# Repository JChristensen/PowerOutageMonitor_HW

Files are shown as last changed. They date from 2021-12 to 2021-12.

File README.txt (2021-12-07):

README file for Arduino-Based Power Outage Logger board v1.2
https://github.com/JChristensen/PowerOutageMonitor_HW
Jack Christensen Dec 2021

This work is licensed under the Creative Commons Attribution-ShareAlike 4.0
International License. To view a copy of this license, visit
https://creativecommons.org/licenses/by-sa/4.0/ or send a letter to
Creative Commons, 171 Second Street, Suite 300, San Francisco, CA 94105, USA.

================================================================================
The version 1.2 board has updated routing which supports RTC 1Hz interrupt
without adding a wire.

An Arduino sketch for the board can be found at:
https://github.com/JChristensen/PowerOutageMonitor_SW

Boards can be ordered from OSH Park,
https://oshpark.com/shared_projects/b4qpXvHG

================================================================================
Assembly notes and options

1. The board is intended to be powered by either a 5V or a 7-12V AC adapter.
When using a 5V adapter, it MUST BE REGULATED; in this case, C1, C2, D1 and U2
do not need to be installed. Set the PWR SEL jumper (JP1) to DIRECT when using a
5V regulated adapter.

2. When disconnected from the power, certain 5V regulated adapters may emit a
power blip that the RTC interprets as a power-up event. This results in the
power-down and power-up timestamps being identical even if the power is left off
for several minutes. To eliminate this, power the RTC from an MCU pin by
selecting MCU power via the RTC PWR jumper (JP2). This is supported by the
sketch referenced above. It is also recommended to set the ATmega328P brown-out
detector to 4.3V by setting the extended fuse byte to 0x04. Note that when the
RTC is powered from the MCU pin, any MCU reset will cause a power outage to be
logged, whether or not it is associated with an actual power outage.

3. The Tinsharp TC1602A-09T 16x2 LCD display uses an LED backlight that requires
only 15mA at 5V. This means that a current-limiting resistor is not needed (use
a jumper in place of R5), and that the backlight can be powered from an MCU pin.
Do not use displays that require more than 20mA to operate the backlight. Note
also that some displays will require a non-zero value for R5 if their backlight
operates on less than 5V.

4. The board includes optional provisions for an on-board temperature sensor and
associated pullup resistor (U3, R6). An optional three-position terminal block
can also connect to an off-board sensor. The Arduino sketch referenced above
contains no code for these optional sensors.

5. Photocell PC1 is used to adjust the display backlight brightness to match the
ambient light level. The Arduino sketch above uses the internal AVR pullup
resistor in association with PC1, but if this does not result in satisfactory
adjustment of the backlight, then the internal pullup can be disabled and an
alternate resistor can be installed at R4.

================================================================================
Power Outage Logger Board
Bill of Materials

Part    Value               Device
C1      47uF                Radial lead electrolytic, 16V, 2 mm lead spacing
C2      100nF               50V MLCC, 0.1 in. lead spacing
C3      47uF                Radial lead electrolytic, 16V, 2 mm lead spacing
C4      100nF               50V MLCC, 0.1 in. lead spacing
C5      100nF               50V MLCC, 0.1 in. lead spacing
C6      100nF               50V MLCC, 0.1 in. lead spacing
C7      100nF               50V MLCC, 0.1 in. lead spacing
C8      27pF                50V MLCC, 0.1 in. lead spacing
C9      27pF                50V MLCC, 0.1 in. lead spacing
C10     100nF               50V MLCC, 0.1 in. lead spacing
D1      1N4004              Silicon rectifier
D2      1N4148              Signal diode
D3      5mm LED
J1      2.1mm power jack
JP1     Supply select       1x3 0.1 in. male header (or use jumper)
JP2     RTC power select    1x3 0.1 in. male header, right angle (or use jumper)
JP3     FTDI                1x6 0.1 in. male header, right angle
JP4     ICSP                2x3 0.1 in. male header (OPTIONAL)
PC1     CdS Photocell
PCB1    MCP79412            MCP79412 RTC Breakout Board, see:
                            https://github.com/JChristensen/rtc79412
PCB2    TC1602A-09T         Tinsharp 16x2 LCD
R1      10K                 1/8W 5% carbon film
R2      10K                 3/8 in. square trimpot, Bourns 3386P or equivalent
R3      330Ω                1/8W 5% carbon film
R4      10K                 1/8W 5% carbon film,
                            OPTIONAL pullup resistor for photocell (sketch uses
                            internal AVR pullup).
R5      0Ω                  1/8W 5% carbon film, current-limiting resistor for
                            LCD backlight.
                            Use a jumper with the TC1602A-09T display. Use
                            appropriate value for other displays.
R6      4.7K                1/8W 5% carbon film,
                            OPTIONAL pullup resistor for temperature/external
                            sensor.
S1      SET                 Omron B3F-312X
S2      UP                  Omron B3F-312X
S3      DN                  Omron B3F-312X
S4      RESET               Omron B3F-1020 (OPTIONAL)
TB1     Ext Sensor          3.5 mm x 3 terminal block, OST-TB-33.5MM or similar,
                            OPTIONAL for external sensor connection.
U1      ATmega328P-PU       Microcontroller
U2      78L05               5V 100mA Voltage Regulator
U3      DS18B20             Temperature Sensor (OPTIONAL)
Y1      16MHz               16MHz 18pF crystal

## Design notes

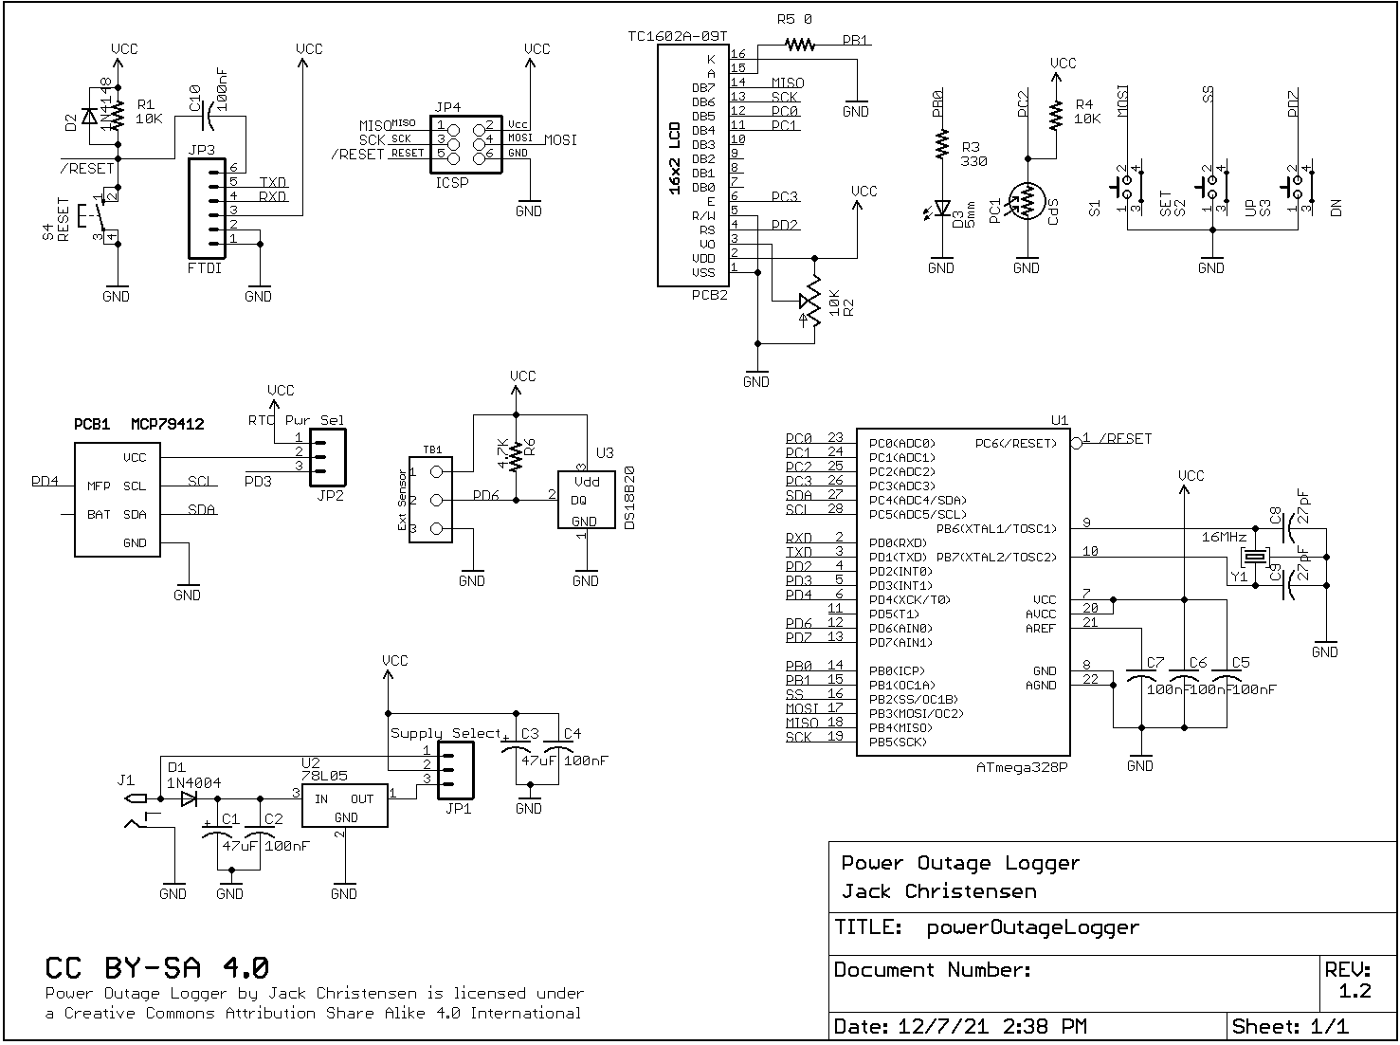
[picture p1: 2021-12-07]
schematic.png

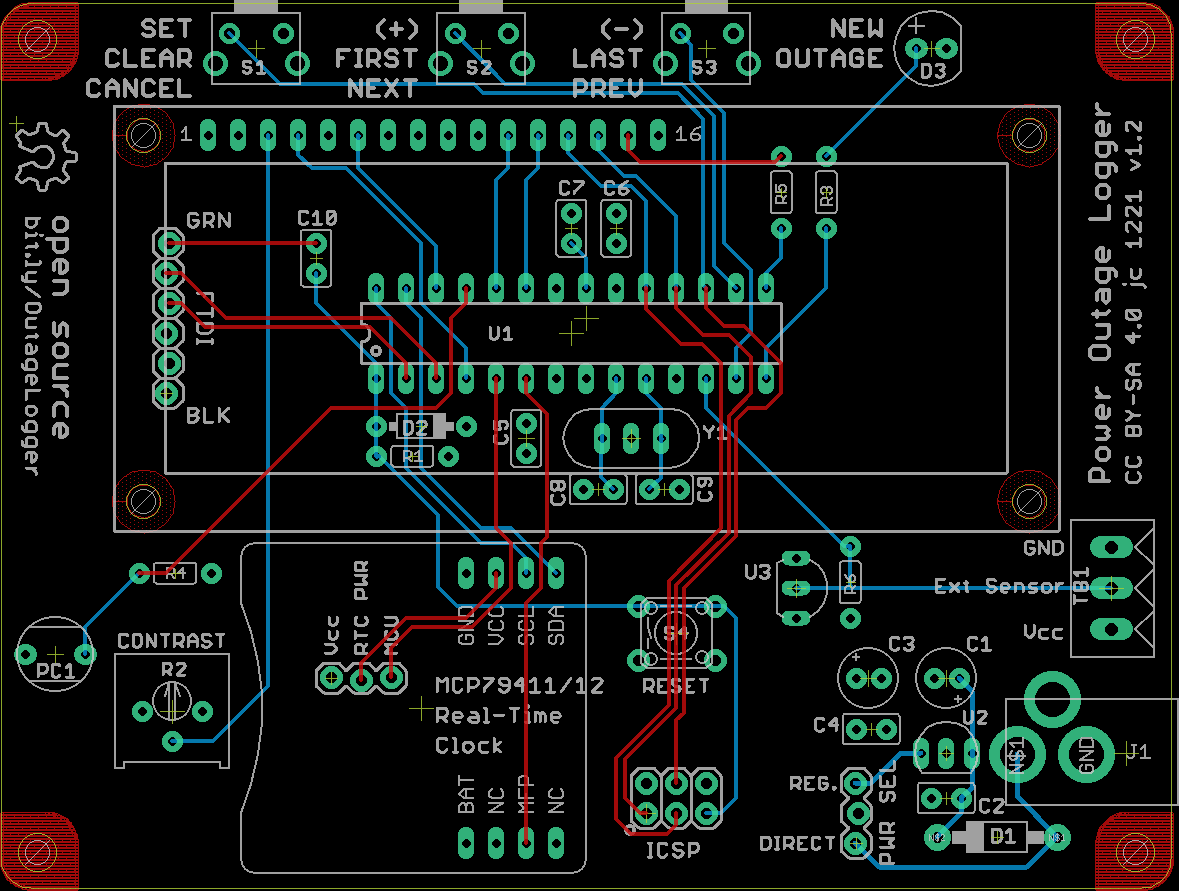
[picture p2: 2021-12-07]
board.png

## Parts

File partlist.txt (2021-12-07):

Partlist

Exported from powerOutageLogger.sch at 12/7/21 3:07 PM

EAGLE Version 9.6.2 Copyright (c) 1988-2020 Autodesk, Inc.

Assembly variant: 

Part     Value          Device             Package           Library  Sheet

C1       47uF           CPOL-USE2-5        E2-5              _jc      1
C2       100nF          C-US025-025X050    C025-025X050      _jc      1
C3       47uF           CPOL-USE2-5        E2-5              _jc      1
C4       100nF          C-US025-025X050    C025-025X050      _jc      1
C5       100nF          C-US025-025X050    C025-025X050      _jc      1
C6       100nF          C-US025-025X050    C025-025X050      _jc      1
C7       100nF          C-US025-025X050    C025-025X050      _jc      1
C8       27pF           C-US025-025X050    C025-025X050      _jc      1
C9       27pF           C-US025-025X050    C025-025X050      _jc      1
C10      100nF          C-US025-025X050    C025-025X050      _jc      1
D1       1N4004         DIODE1N400X        1N400X            _jc      1
D2       1N4148         DIODE1N4148        1N4148            _jc      1
D3       5mm            LED5MM             LED5MM            _jc      1
J1       2.1MMJACKTHM   2.1MMJACKTHM       PJ-102A           adafruit 1
JP1      Supply Select  M03LOCK            1X03_LOCK         SparkFun 1
JP2      RTC Pwr Sel    M03LOCK            1X03_LOCK         SparkFun 1
JP3      FTDI           M06LOCK            1X06_LOCK         SparkFun 1
JP4      ICSP           AVR_SPI_PRG_6PTH   2X3               _jc      1
PC1      CdS            PHOTOCELL020-017   PHOTOCELL-020-017 _jc      1
PCB1     MCP79412       RTC79412           RTC79412          _jc      1
PCB2     TC1602A-09T    LCD-16X2           LCD-16X2          SparkFun 1
R1       10K            R-US_0204/6        0204/6            _jc      1
R2       10K            TRIMPOT-3386P3386P TRIMPOT-3386P     _jc      1
R3       330            R-US_0204/6        0204/6            _jc      1
R4       10K            R-US_0204/6        0204/6            _jc      1
R5       0              R-US_0204/6        0204/6            _jc      1
R6       4.7K           R-US_0204/6        0204/6            _jc      1
S1       SET            B3F-312X           B3F-312X          _jc      1
S2       UP             B3F-312X           B3F-312X          _jc      1
S3       DN             B3F-312X           B3F-312X          _jc      1
S4       RESET          10-XXOCT           B3F-10XXOCT       _jc      1
TB1      Ext Sensor     OST-TB-33.5MM      OST-TB-3-3.5MM    _jc      1
U1       ATmega328P     AVR-MEGA8-PPTH     DIL28-3           SparkFun 1
U2       78L05          78XX-HTO92         TO92-INLINE       _jc      1
U3       DS18B20        DS18B20            TO92-OVAL         _jc      1
Y1       16MHz          RESONATOR          RESONATOR         _jc      1

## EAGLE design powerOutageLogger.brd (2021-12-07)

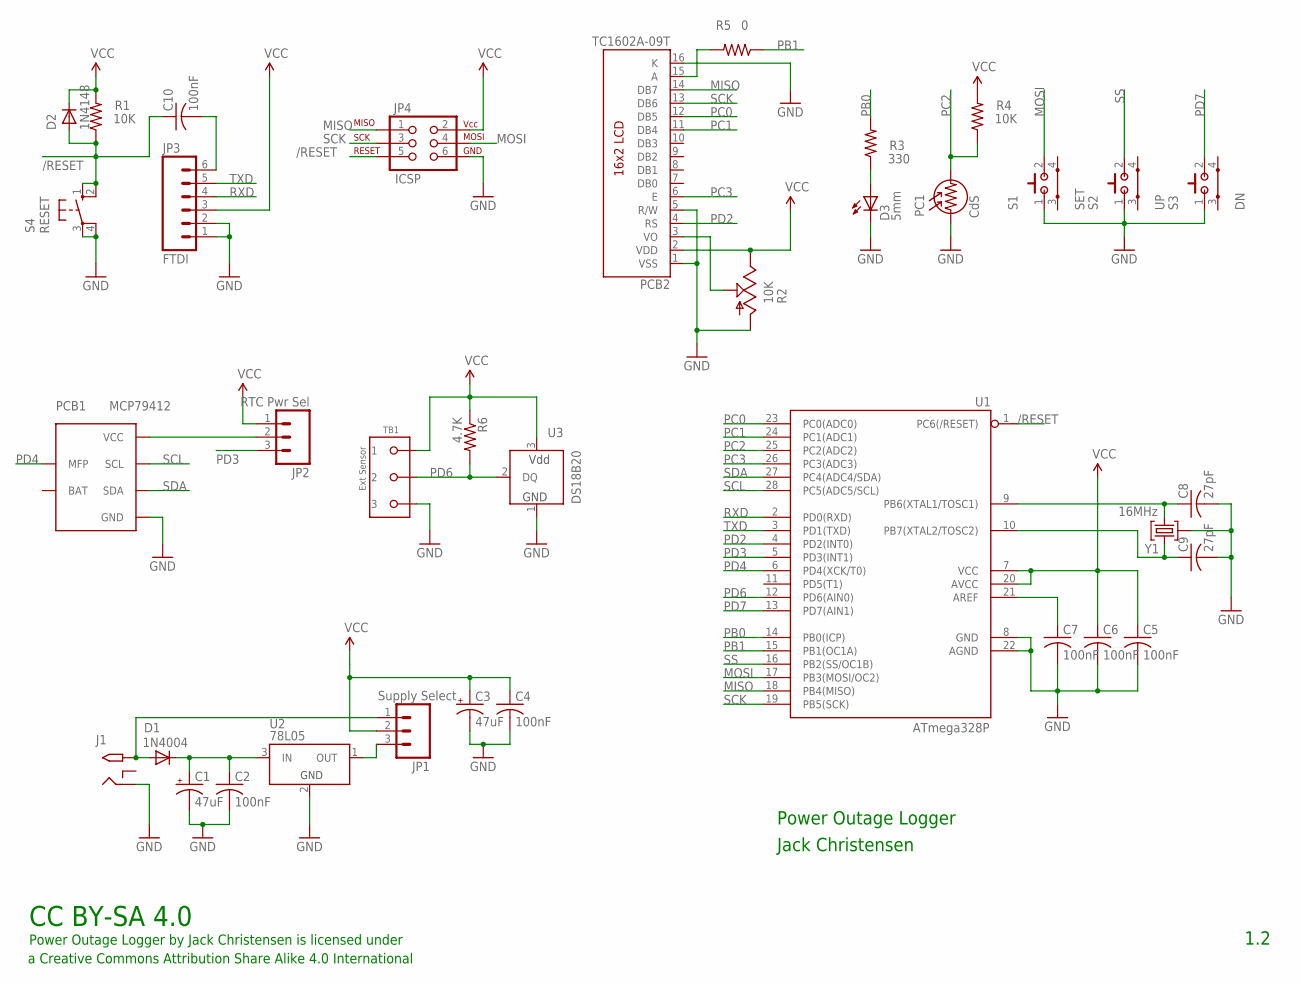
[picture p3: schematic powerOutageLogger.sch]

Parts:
C1, C3: 47uF; E2-5
C2, C4, C5, C6, C7, C10: 100nF; C025-025X050
C8, C9: 27pF; C025-025X050
D1: 1N4004; 1N400X
D2: 1N4148
D3: 5mm; LED5MM
J1: 2.1MMJACKTHM; PJ-102A
JP1: Supply Select; 1X03_LOCK
JP2: RTC Pwr Sel; 1X03_LOCK
JP3: FTDI; 1X06_LOCK
JP4: ICSP; 2X3
PC1: CdS; PHOTOCELL-020-017
PCB1: MCP79412; RTC79412
PCB2: TC1602A-09T; LCD-16X2
R1, R4: 10K; 0204/6
R2: 10K; TRIMPOT-3386P
R3: 330; 0204/6
R5: 0; 0204/6
R6: 4.7K; 0204/6
S1: SET; B3F-312X
S2: UP; B3F-312X
S3: DN; B3F-312X
S4: RESET; B3F-10XXOCT
TB1: Ext Sensor; OST-TB-3-3.5MM
U1: ATmega328P; DIL28-3
U2: 78L05; TO92-INLINE
U3: DS18B20; TO92-OVAL
Y1: 16MHz; RESONATOR

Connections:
/RESET: C10.1, D2.A, JP4.5, R1.1, S4.1 (S), S4.2 (S1), U1.1 (PC6(/RESET))
GND: C1.-, C2.2, C3.-, C4.2, C5.2, C6.2, C7.2, C8.2, C9.2, D3.K (C), J1.RING, JP3.1, JP3.2, JP4.6, PC1.P$1 (1), PCB1.8 (GND), PCB2.1 (VSS), PCB2.5 (R/W), PCB2.16 (K), R2.3 (A), S1.1, S2.1, S3.1, S4.3, S4.4 (P1), TB1.P$3 (3), U1.8 (GND), U1.22 (AGND), U2.2 (GND), U3.1 (GND), Y1.2
MISO: JP4.1, PCB2.14 (DB7), U1.18 (PB4(MISO))
MOSI: JP4.4, S1.2, U1.17 (PB3(MOSI/OC2))
unnamed: D1.A, J1.TIP, JP1.1
unnamed: C1.+, C2.1, D1.K, U2.3 (IN)
unnamed: PCB2.3 (VO), R2.2 (S)
unnamed: D3.A, R3.1
unnamed: JP2.2, PCB1.7 (VCC)
unnamed: PCB2.15 (A), R5.2
unnamed: C7.1, U1.21 (AREF)
OUT: JP1.3, U2.1 (OUT)
PB0: R3.2, U1.14 (PB0(ICP))
PB1: R5.1, U1.15 (PB1(OC1A))
PC0: PCB2.12 (DB5), U1.23 (PC0(ADC0))
PC1: PCB2.11 (DB4), U1.24 (PC1(ADC1))
PC2: PC1.P$2 (2), R4.1, U1.25 (PC2(ADC2))
PC3: PCB2.6 (E), U1.26 (PC3(ADC3))
PD2: PCB2.4 (RS), U1.4 (PD2(INT0))
PD3: JP2.3, U1.5 (PD3(INT1))
PD4: PCB1.3 (MFP), U1.6 (PD4(XCK/T0))
PD6: R6.2, TB1.P$2 (2), U1.12 (PD6(AIN0)), U3.2 (DQ)
PD7: S3.2, U1.13 (PD7(AIN1))
RST: C10.2, JP3.6
RXD: JP3.4, U1.2 (PD0(RXD))
SCK: JP4.3, PCB2.13 (DB6), U1.19 (PB5(SCK))
SCL: PCB1.6 (SCL), U1.28 (PC5(ADC5/SCL))
SDA: PCB1.5 (SDA), U1.27 (PC4(ADC4/SDA))
SS: S2.2, U1.16 (PB2(SS/OC1B))
TXD: JP3.5, U1.3 (PD1(TXD))
VCC: C3.+, C4.1, C5.1, C6.1, D2.K, JP1.2, JP2.1, JP3.3, JP4.2, PCB2.2 (VDD), R1.2, R2.1 (E), R4.2, R6.1, TB1.P$1 (1), U1.7 (VCC), U1.20 (AVCC), U3.3 (VDD)
XTAL1: C9.1, U1.10 (PB7(XTAL2/TOSC2)), Y1.1
XTAL2: C8.1, U1.9 (PB6(XTAL1/TOSC1)), Y1.3

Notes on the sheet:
Power Outage Logger by Jack Christensen is licensed under
CC BY-SA 4.0
a Creative Commons Attribution Share Alike 4.0 International
Power Outage Logger
Jack Christensen
1.2

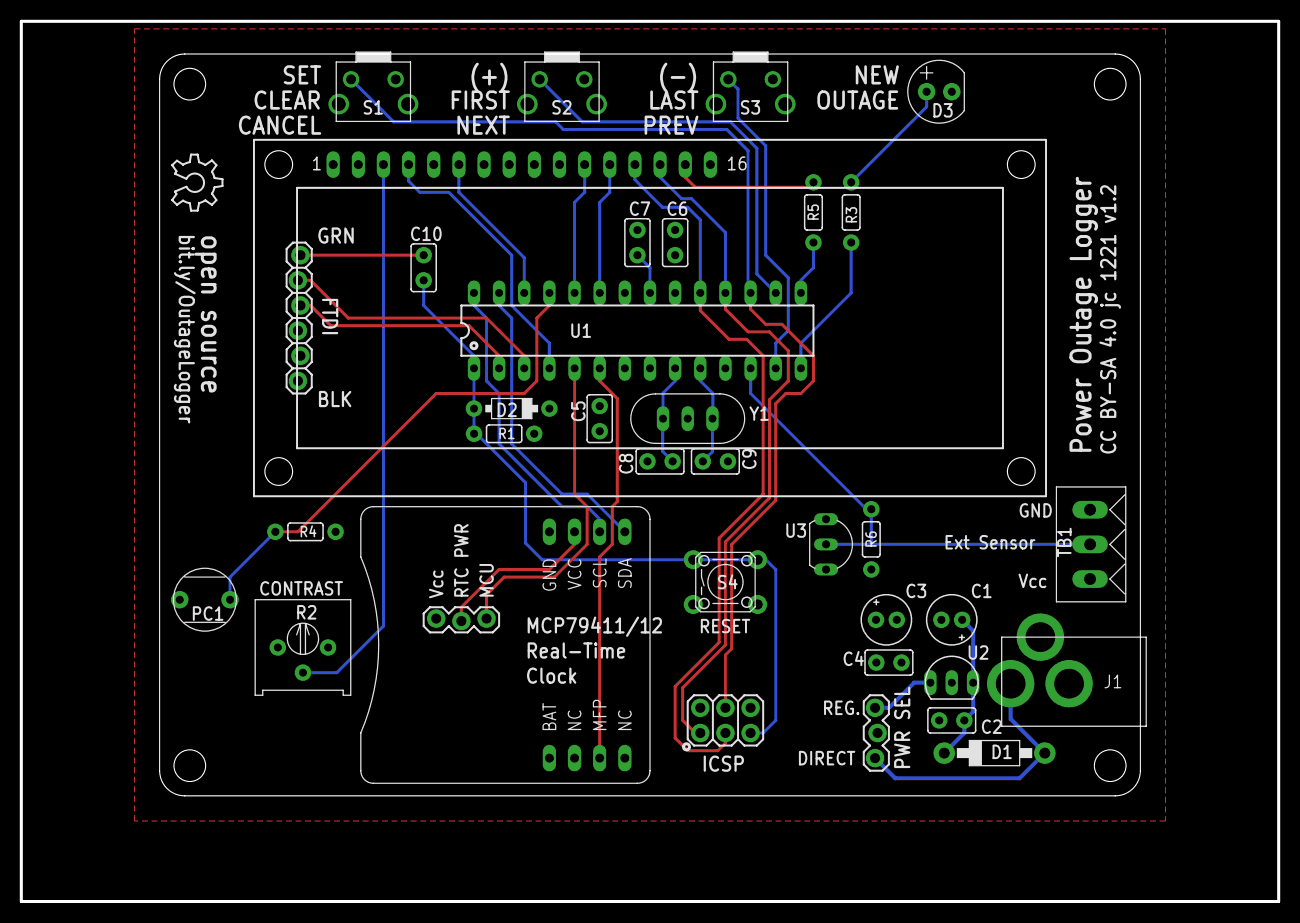
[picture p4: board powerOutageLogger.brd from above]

Board: 2 copper layers, 127.0 x 88.9 mm, 38 parts (1 on the bottom side), 33 nets.

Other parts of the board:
U$1, U$2: OSHW_8X200_NOTEXT

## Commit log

2012-09-28 Version 1.1 Added ReadMe.txt Added schematic.png
    [powerOutageLogger.brd, powerOutageLogger.sch]
2012-10-03 Minor trace tweaks.
    [powerOutageLogger.brd]
2012-10-04 Final layout as sent to fab.
    [powerOutageLogger.brd]
2012-11-07 Move labels on schematic for readability.
    [powerOutageLogger.sch]
2014-02-14 Minor routing changes, fix hyperlinks in ReadMe.txt.
    [powerOutageLogger.brd]
2021-12-07 Update for Eagle v9, Add gerbers.zip, board image, partlist.txt, Update ReadMe.
    [powerOutageLogger.brd]
2021-12-07 Improved board routing, added connection for RTC interrupt.
    [powerOutageLogger.brd, powerOutageLogger.sch]

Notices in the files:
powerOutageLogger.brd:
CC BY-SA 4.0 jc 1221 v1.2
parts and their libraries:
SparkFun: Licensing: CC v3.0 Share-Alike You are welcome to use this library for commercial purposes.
